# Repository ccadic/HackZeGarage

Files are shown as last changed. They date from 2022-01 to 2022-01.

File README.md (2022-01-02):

# HackZeGarage
ESP32-S2 and CC1101S 433Mhz usb stick to record and send car gates/garages data keys and open stuff

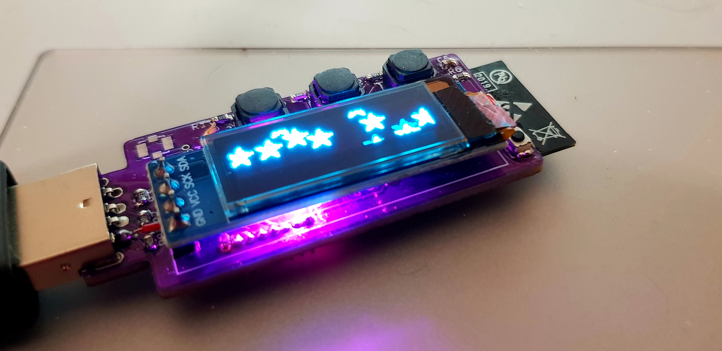
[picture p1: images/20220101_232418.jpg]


**HackZeGarage

@sulfuroid / Dr CADIC Philippe
Portable USB Stick to replace garage doors and gate doors remote controls into one single 433 Mhz C1101 transceiver device. Data bank of gates digital signatures. 

The ESP32 C1101 USB stick to ease the access to garages and parkings using 433 Mhz remote keys. HackZeGarage is a USB stick with ESP32 S2, battery and charging module with 3 buttons and a SSD1306 Oled display. This item can also be used as a passwords data bank.

**UPLOADING SKETCHES**

Uploading sketches onto an ESP32S2 is a bit tricky. You have to plug the device onto the USB port of the PC running Arduino IDE. Then, you have to press RST and BOOT micro switch respecting this order :
1.	Press both  RESET & BOOT switches
2.	Release RESET switch
3.	Then release BOOT
If it is done properly , you should ear the computer recognize the device and a COMx port should appear.

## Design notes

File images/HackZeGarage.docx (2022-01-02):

HackZeGarage
@sulfuroid / Dr CADIC Philippe

Portable USB Stick to replace garage doors and gate doors remote controls into one single 433 Mhz C1101 transceiver device. Data bank of gates digital signatures.

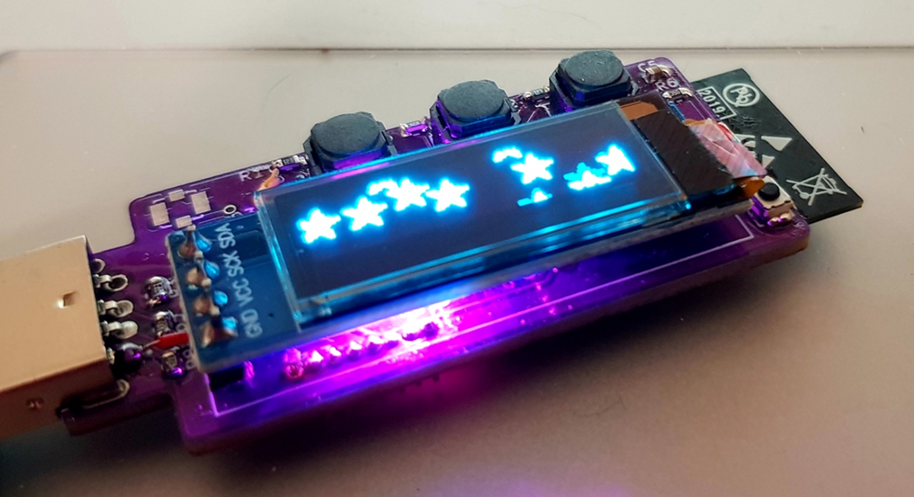
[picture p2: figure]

The ESP32 C1101 USB stick to ease the access to garages and parkings using 433 Mhz remote keys. HackZeGarage is a USB stick with ESP32 S2, battery and charging module with 3 buttons and a SSD1306 Oled display. This item can also be used as a password data bank.

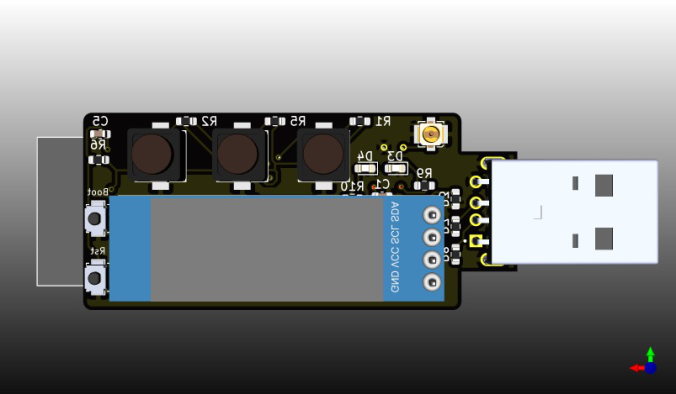
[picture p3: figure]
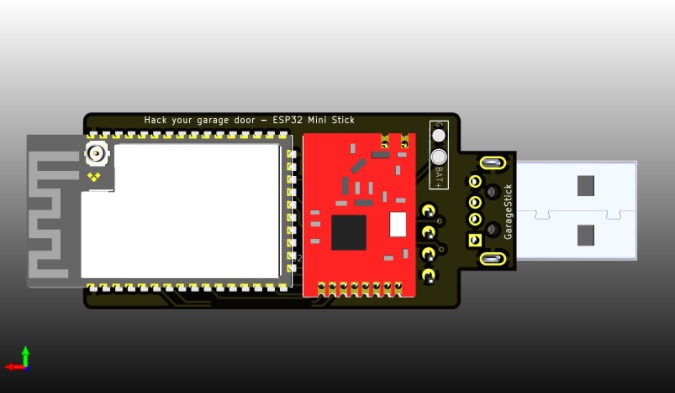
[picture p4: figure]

List of components

- 2 micro switches for ESP32 BOOT/RESET options
- 3 buttons on the top of the display
  - SW1/BUTTON3/GPIO 01
  - SW4/BUTTON1/GPIO 15
  - SW5/BUTTON2/GPIO 16
- 2 configurable LEDs
  - D3 : GPIO 21
  - D4 : GPIO 14
- A 128x32 SSD1306 OLD Display (I2C connected). The display’s power is controlled by GPIO 06
- A 433 MHZ SPI transceiver module. This device is also power controlled with GPIO 7

Schematic diagram

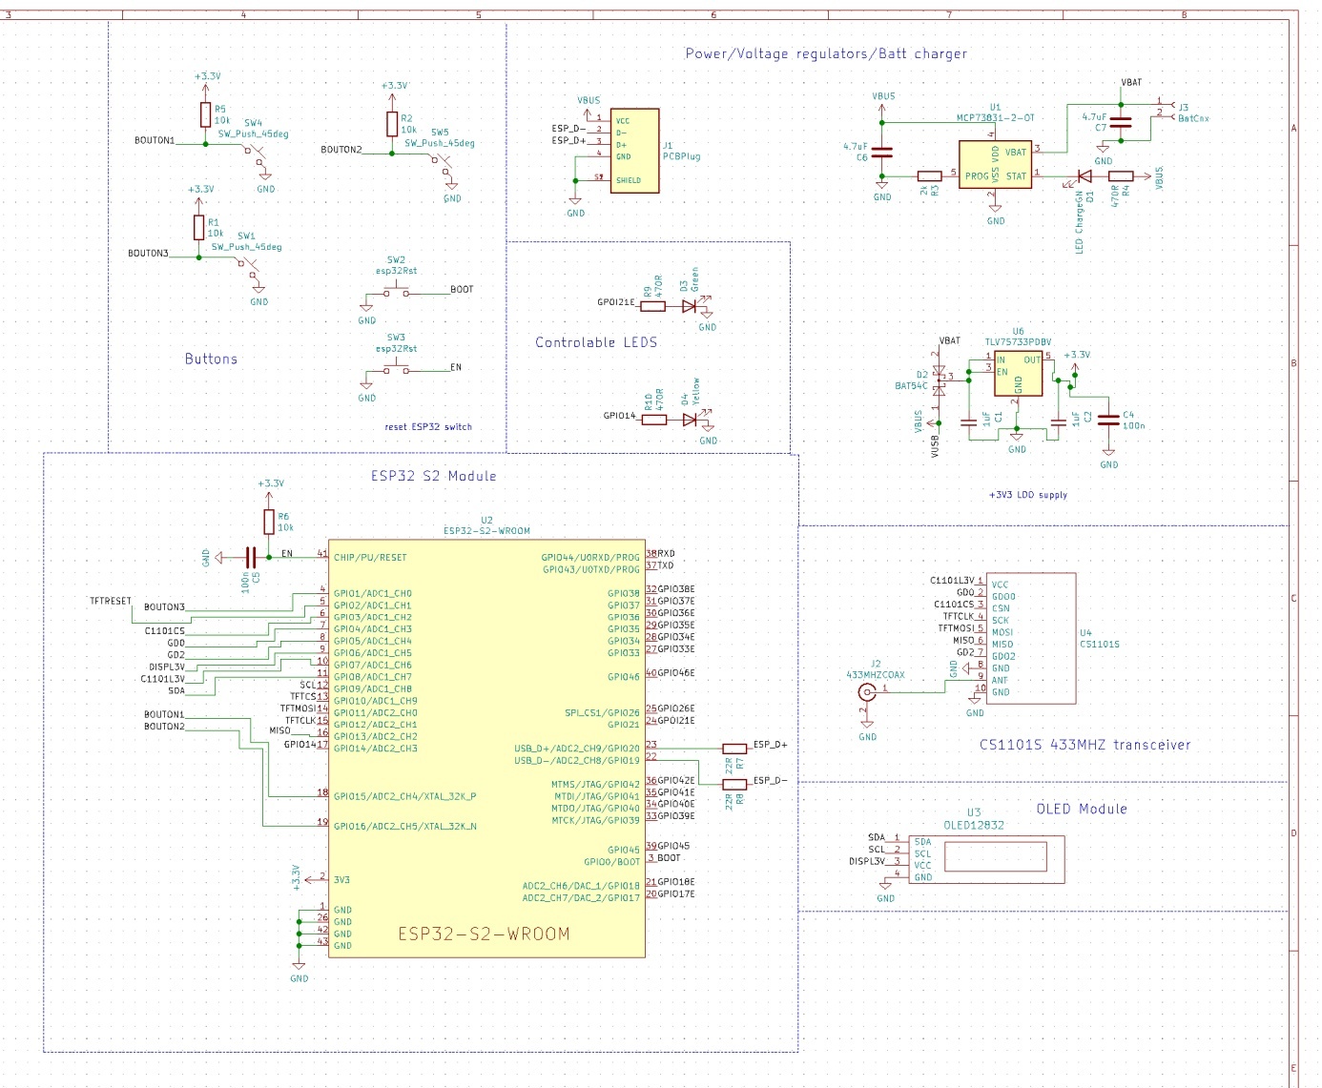
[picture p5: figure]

UPLOADING SKETCHES

Uploading sketches onto an ESP32S2 is a bit tricky. You have to plug the device onto the USB port of the PC running Arduino IDE. Then, you have to press RST and BOOT micro switch respecting this order :

1. Press both RESET & BOOT switches
2. Release RESET switch
3. Then release BOOT

If it is done properly , you should ear the computer recognize the device and a COMx port should appear.

ARDUINO IDE setup

The ESP32S2 is capable or direct USB connection. You have to select ESP32S2 DEV MODULE and select the option as shown in the image above.

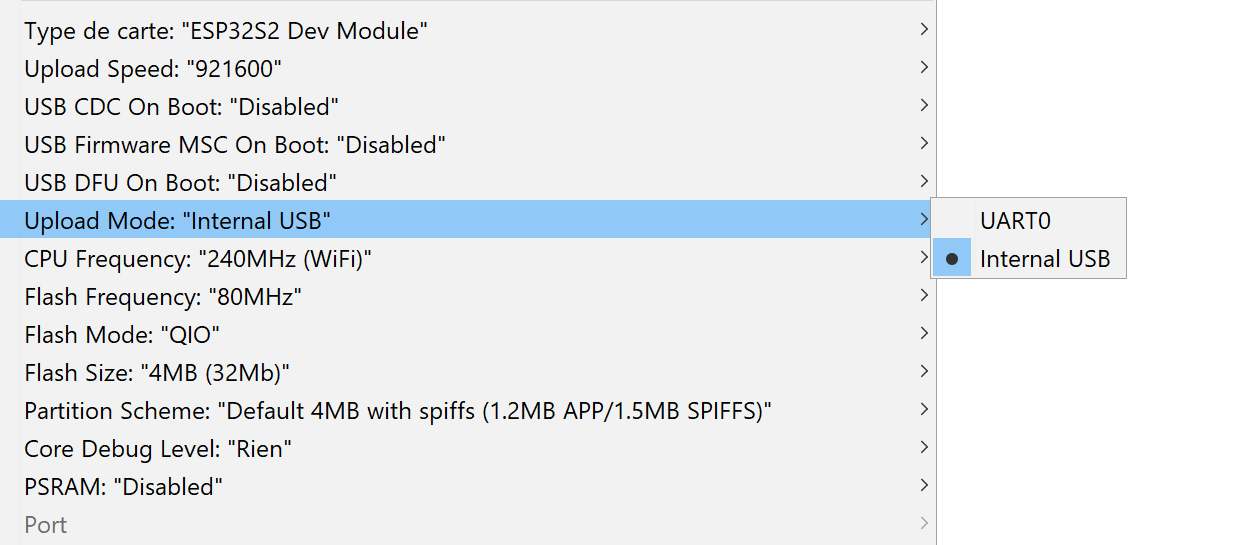
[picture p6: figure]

BOM : see BOM.XLS

This board has been designed to keep the budget as low as possible. Most of the components are classic components you may find everywhere.

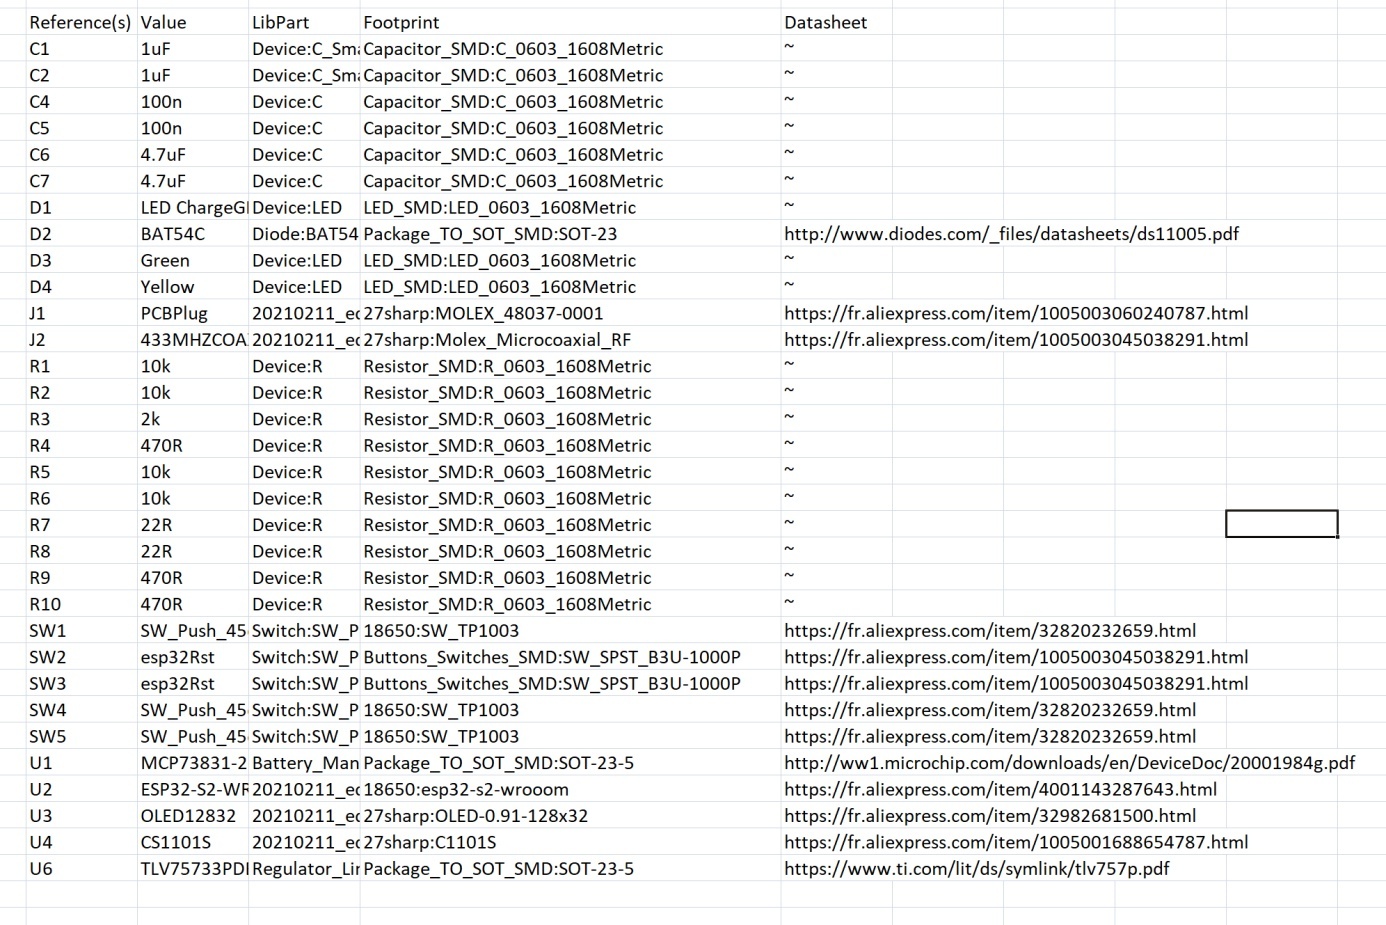
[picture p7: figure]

Important note:

You may get the 0.3 version of the board which has to issues you can easily fix. Beside this fix, there is no difference with V1 version. To protect the environment of our planet, we decided not to through the 50 V0.3 PCB to the bin as the fix is minor. If you get the V0.3 version, you will need to add 2 extra wires when assembling the device. See diagram above.

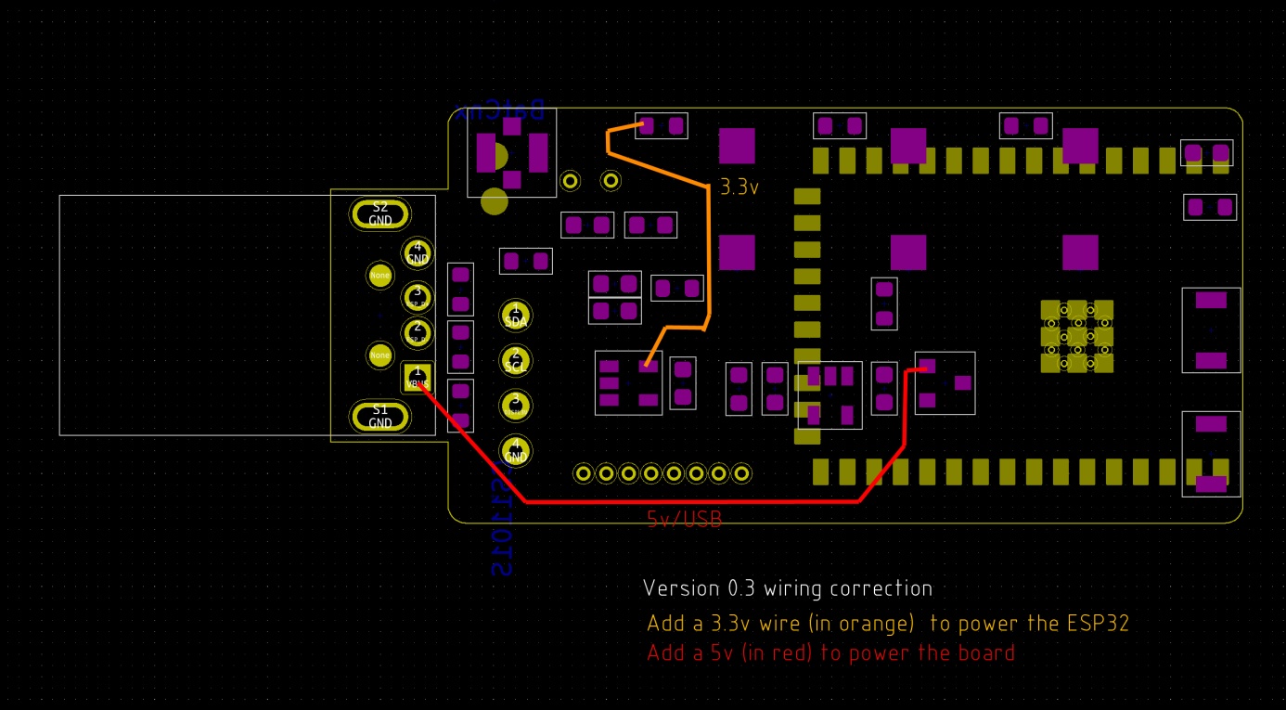
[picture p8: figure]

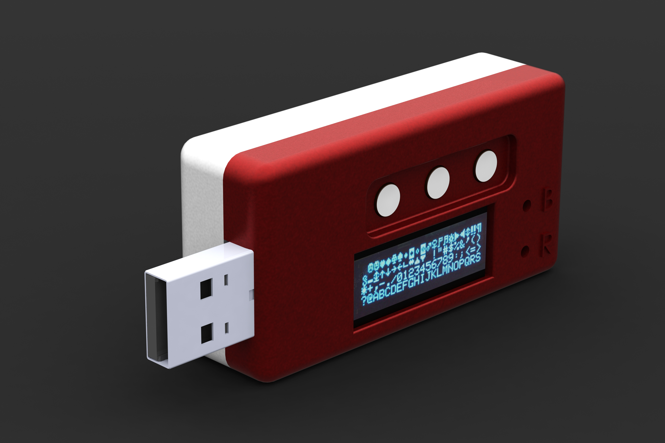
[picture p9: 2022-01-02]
allstuff3.JPG

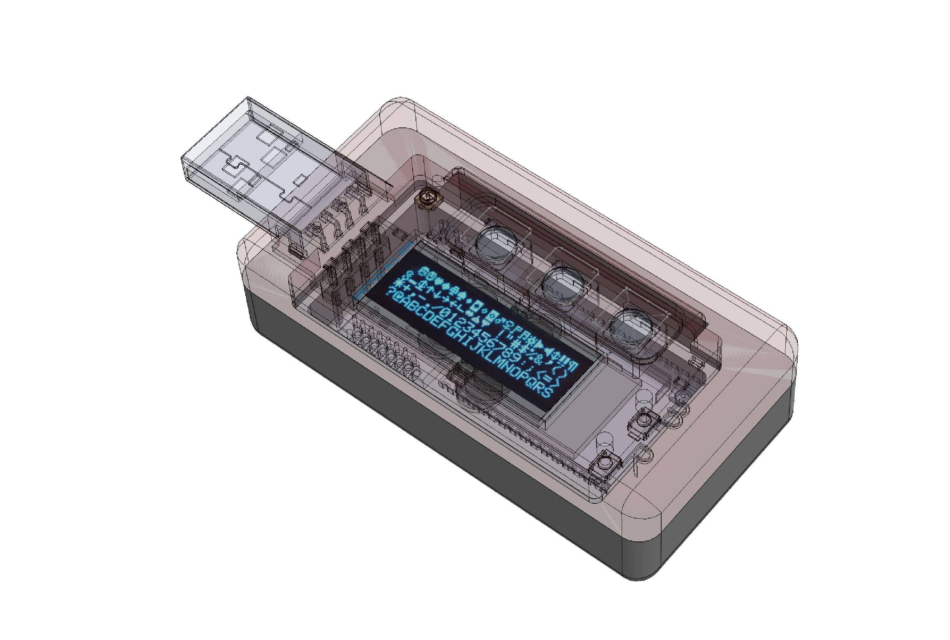
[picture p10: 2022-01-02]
allstuff4.JPG

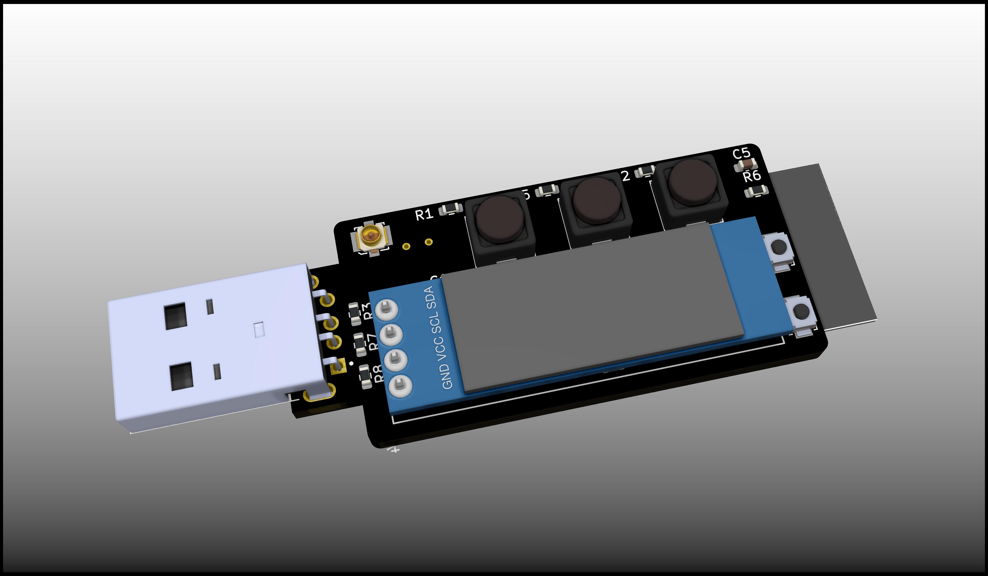
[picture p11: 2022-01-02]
images/keyring.jpg

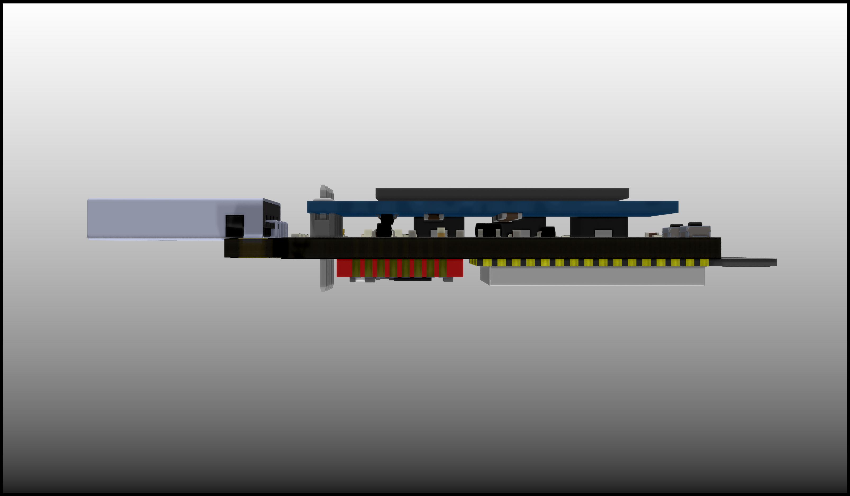
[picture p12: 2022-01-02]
images/keyringgarage4.jpg

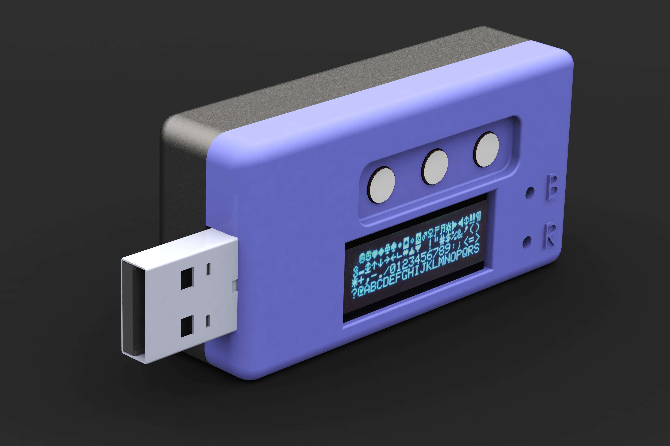
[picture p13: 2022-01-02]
allstuff5.JPG

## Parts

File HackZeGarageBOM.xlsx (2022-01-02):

Source: | C:\Users\ccadic\CloudStation\garagehack\version2\20210211_eduino.sch
Date: | 2022-01-02 14:31
Tool: | Eeschema (5.1.12)-1
Generator: | C:\Program Files\KiCad\bin\scripting\plugins/bom_csv_grouped_by_value.py
Component Count: | 33
Individual Components:
Item | Qty | Reference(s) | Value | LibPart | Footprint | Datasheet
 |  | C1 | 1uF | Device:C_Small | Capacitor_SMD:C_0603_1608Metric | ~
 |  | C2 | 1uF | Device:C_Small | Capacitor_SMD:C_0603_1608Metric | ~
 |  | C4 | 100n | Device:C | Capacitor_SMD:C_0603_1608Metric | ~
 |  | C5 | 100n | Device:C | Capacitor_SMD:C_0603_1608Metric | ~
 |  | C6 | 4.7uF | Device:C | Capacitor_SMD:C_0603_1608Metric | ~
 |  | C7 | 4.7uF | Device:C | Capacitor_SMD:C_0603_1608Metric | ~
 |  | D1 | LED ChargeGN | Device:LED | LED_SMD:LED_0603_1608Metric | ~
 |  | D2 | BAT54C | Diode:BAT54C | Package_TO_SOT_SMD:SOT-23 | http://www.diodes.com/_files/datasheets/ds11005.pdf
 |  | D3 | Green | Device:LED | LED_SMD:LED_0603_1608Metric | ~
 |  | D4 | Yellow | Device:LED | LED_SMD:LED_0603_1608Metric | ~
 |  | J1 | PCBPlug | 20210211_eduino-rescue:48037-0001-4g_ant | 27sharp:MOLEX_48037-0001 | https://fr.aliexpress.com/item/1005003060240787.html
 |  | J2 | 433MHZCOAX | 20210211_eduino-rescue:Conn_Coaxial-ConnectorPCI-conn_coaxial-connectorpci | 27sharp:Molex_Microcoaxial_RF | https://fr.aliexpress.com/item/1005003045038291.html
 |  | R1 | 10k | Device:R | Resistor_SMD:R_0603_1608Metric | ~
 |  | R2 | 10k | Device:R | Resistor_SMD:R_0603_1608Metric | ~
 |  | R3 | 2k | Device:R | Resistor_SMD:R_0603_1608Metric | ~
 |  | R4 | 470R | Device:R | Resistor_SMD:R_0603_1608Metric | ~
 |  | R5 | 10k | Device:R | Resistor_SMD:R_0603_1608Metric | ~
 |  | R6 | 10k | Device:R | Resistor_SMD:R_0603_1608Metric | ~
 |  | R7 | 22R | Device:R | Resistor_SMD:R_0603_1608Metric | ~
 |  | R8 | 22R | Device:R | Resistor_SMD:R_0603_1608Metric | ~
 |  | R9 | 470R | Device:R | Resistor_SMD:R_0603_1608Metric | ~
 |  | R10 | 470R | Device:R | Resistor_SMD:R_0603_1608Metric | ~
 |  | SW1 | SW_Push_45deg | Switch:SW_Push_45deg | 18650:SW_TP1003 | https://fr.aliexpress.com/item/32820232659.html
 |  | SW2 | esp32Rst | Switch:SW_Push | Buttons_Switches_SMD:SW_SPST_B3U-1000P | https://fr.aliexpress.com/item/1005003045038291.html
 |  | SW3 | esp32Rst | Switch:SW_Push | Buttons_Switches_SMD:SW_SPST_B3U-1000P | https://fr.aliexpress.com/item/1005003045038291.html
 |  | SW4 | SW_Push_45deg | Switch:SW_Push_45deg | 18650:SW_TP1003 | https://fr.aliexpress.com/item/32820232659.html
 |  | SW5 | SW_Push_45deg | Switch:SW_Push_45deg | 18650:SW_TP1003 | https://fr.aliexpress.com/item/32820232659.html
 |  | U1 | MCP73831-2-OT | Battery_Management:MCP73831-2-OT | Package_TO_SOT_SMD:SOT-23-5 | http://ww1.microchip.com/downloads/en/DeviceDoc/20001984g.pdf
 |  | U2 | ESP32-S2-WROOM | 20210211_eduino-rescue:ESP32-S2-WROOM-EspressifC3 | 18650:esp32-s2-wrooom | https://fr.aliexpress.com/item/4001143287643.html
 |  | U3 | OLED12832 | 20210211_eduino-rescue:OLED12832-oled12832 | 27sharp:OLED-0.91-128x32 | https://fr.aliexpress.com/item/32982681500.html
 |  | U4 | CS1101S | 20210211_eduino-rescue:CS1101S-CS1101S | 27sharp:C1101S | https://fr.aliexpress.com/item/1005001688654787.html
 |  | U6 | TLV75733PDBV | Regulator_Linear:TLV75733PDBV | Package_TO_SOT_SMD:SOT-23-5 | https://www.ti.com/lit/ds/symlink/tlv757p.pdf
Collated Components:
Item | Qty | Reference(s) | Value | LibPart | Footprint | Datasheet
1 | 2 | C1; C2 | 1uF | Device:C_Small | Capacitor_SMD:C_0603_1608Metric | ~
2 | 2 | C4; C5 | 100n | Device:C | Capacitor_SMD:C_0603_1608Metric | ~
3 | 2 | C6; C7 | 4.7uF | Device:C | Capacitor_SMD:C_0603_1608Metric | ~
4 | 1 | D1 | LED ChargeGN | Device:LED | LED_SMD:LED_0603_1608Metric | ~
5 | 1 | D2 | BAT54C | Diode:BAT54C | Package_TO_SOT_SMD:SOT-23 | http://www.diodes.com/_files/datasheets/ds11005.pdf
6 | 1 | D3 | Green | Device:LED | LED_SMD:LED_0603_1608Metric | ~
7 | 1 | D4 | Yellow | Device:LED | LED_SMD:LED_0603_1608Metric | ~
8 | 1 | J1 | PCBPlug | 20210211_eduino-rescue:48037-0001-4g_ant | 27sharp:MOLEX_48037-0001
9 | 1 | J2 | 433MHZCOAX | 20210211_eduino-rescue:Conn_Coaxial-ConnectorPCI-conn_coaxial-connectorpci | 27sharp:Molex_Microcoaxial_RF
10 | 1 | J3 | BatCnx | Connector:Conn_01x02_Female | 18650:2pads | ~
11 | 4 | R1; R2; R5; R6 | 10k | Device:R | Resistor_SMD:R_0603_1608Metric | ~
12 | 1 | R3 | 2k | Device:R | Resistor_SMD:R_0603_1608Metric | ~
13 | 3 | R4; R9; R10 | 470R | Device:R | Resistor_SMD:R_0603_1608Metric | ~
14 | 2 | R7; R8 | 22R | Device:R | Resistor_SMD:R_0603_1608Metric | ~
15 | 3 | SW1; SW4; SW5 | SW_Push_45deg | Switch:SW_Push_45deg | 18650:SW_TP1003 | ~
16 | 2 | SW2; SW3 | esp32Rst | Switch:SW_Push | Buttons_Switches_SMD:SW_SPST_B3U-1000P | ~
17 | 1 | U1 | MCP73831-2-OT | Battery_Management:MCP73831-2-OT | Package_TO_SOT_SMD:SOT-23-5 | http://ww1.microchip.com/downloads/en/DeviceDoc/20001984g.pdf
18 | 1 | U2 | ESP32-S2-WROOM | 20210211_eduino-rescue:ESP32-S2-WROOM-EspressifC3 | 18650:esp32-s2-wrooom
19 | 1 | U3 | OLED12832 | 20210211_eduino-rescue:OLED12832-oled12832 | 27sharp:OLED-0.91-128x32
20 | 1 | U4 | CS1101S | 20210211_eduino-rescue:CS1101S-CS1101S | 27sharp:C1101S
21 | 1 | U6 | TLV75733PDBV | Regulator_Linear:TLV75733PDBV | Package_TO_SOT_SMD:SOT-23-5 | https://www.ti.com/lit/ds/symlink/tlv757p.pdf

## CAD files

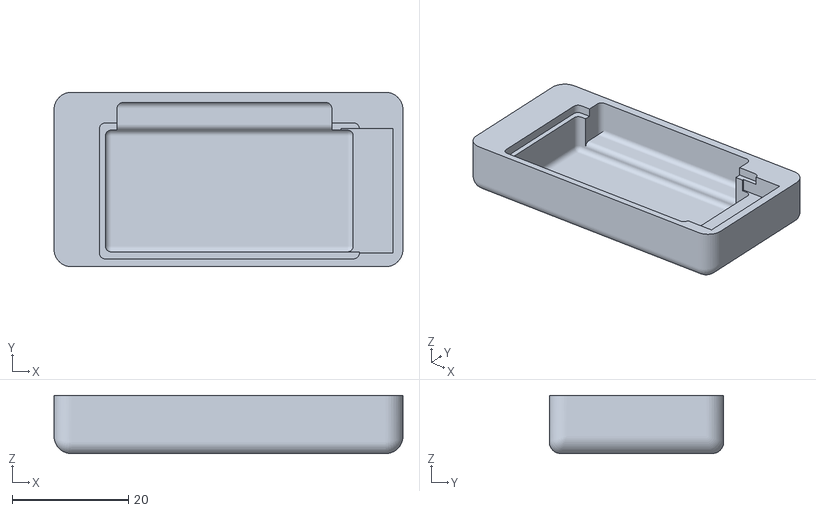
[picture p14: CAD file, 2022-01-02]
stl/coqueinf-batt.STL
60.0 x 30.0 x 10.0

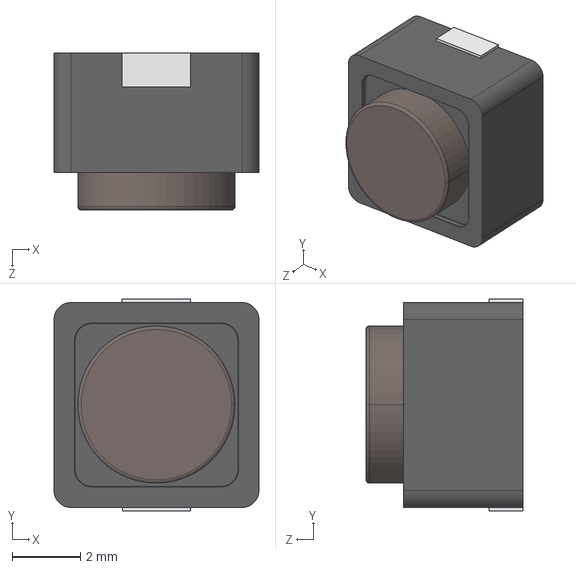
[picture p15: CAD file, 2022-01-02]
TP1003.STEP
6.00 x 6.20 x 4.60 mm

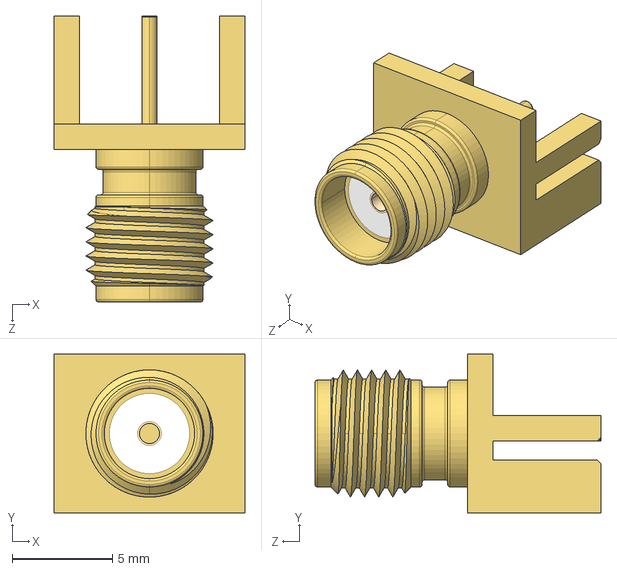
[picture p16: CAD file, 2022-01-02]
sma_fem.STEP
9.52 x 7.92 x 14.3 mm

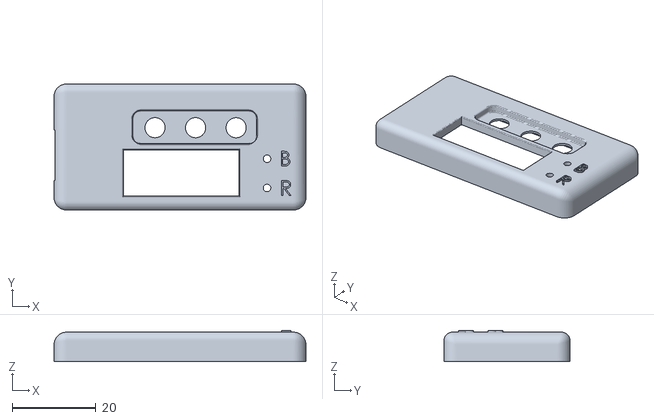
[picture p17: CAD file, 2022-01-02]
stl/coque sup.STL
60.0 x 30.0 x 7.40

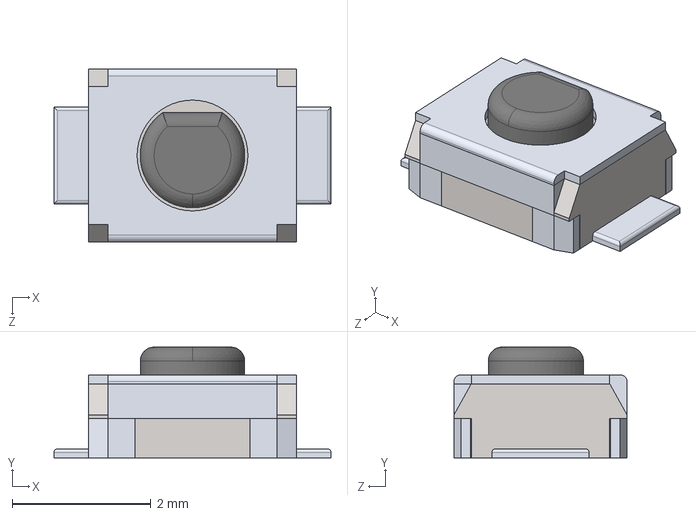
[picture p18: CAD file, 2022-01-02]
B3U1000P.step
4.00 x 1.60 x 2.50 mm

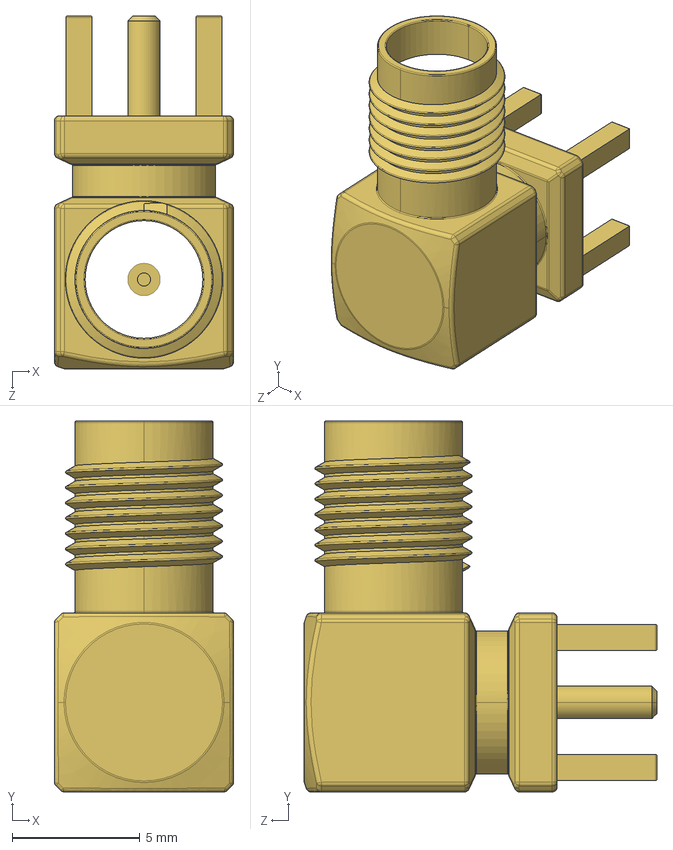
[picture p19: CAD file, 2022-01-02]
SMA-angled.STEP
7.00 x 14.5 x 13.8 mm

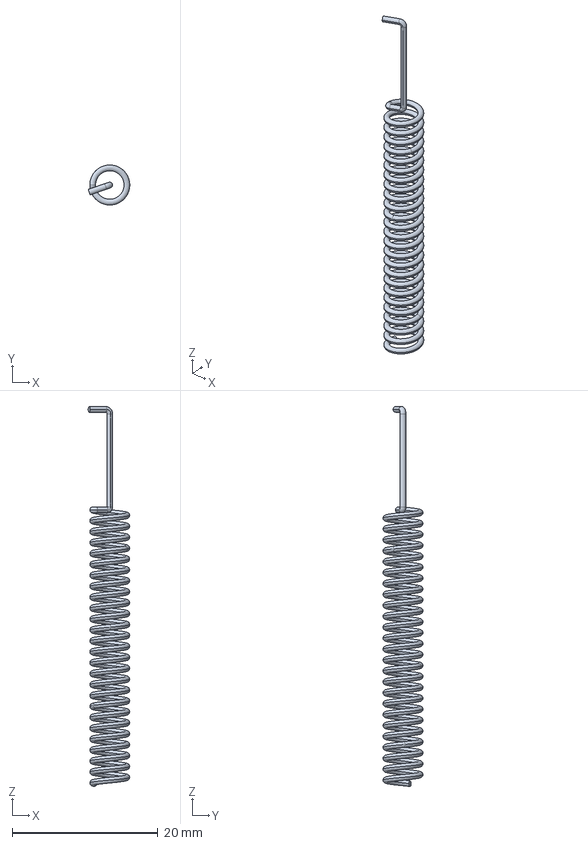
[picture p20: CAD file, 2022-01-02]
433mhz_antenna_bended.stp
5.72 x 5.50 x 52.2 mm

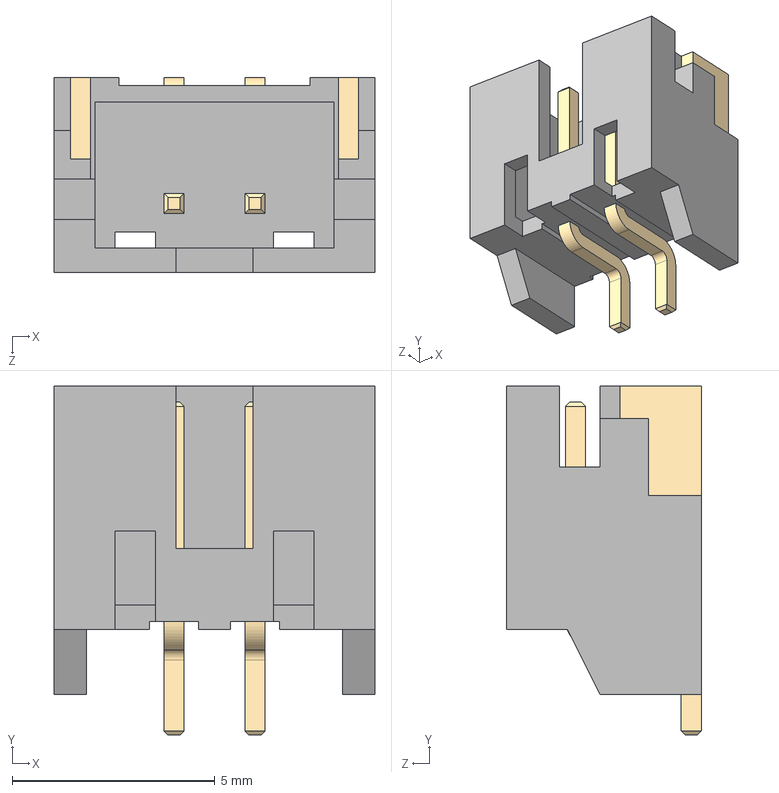
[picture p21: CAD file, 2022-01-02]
JST-PH 2-Pin.STEP
7.90 x 8.60 x 4.80 mm

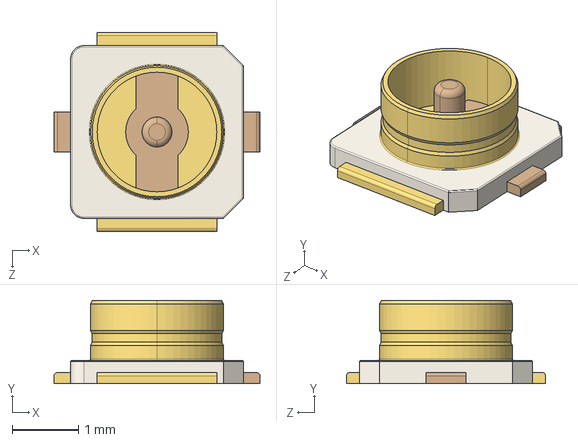
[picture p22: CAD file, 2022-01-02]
coax.STEP
3.10 x 1.25 x 3.00 mm

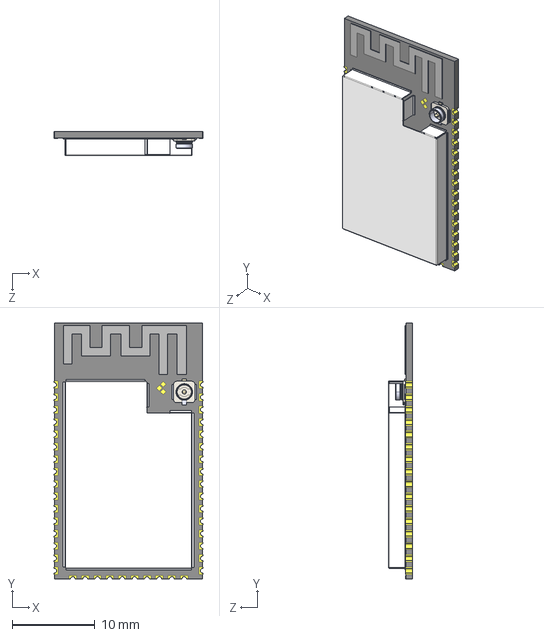
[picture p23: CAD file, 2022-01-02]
ESP32-S2-WROVER.STEP
18.0 x 31.0 x 2.91 mm

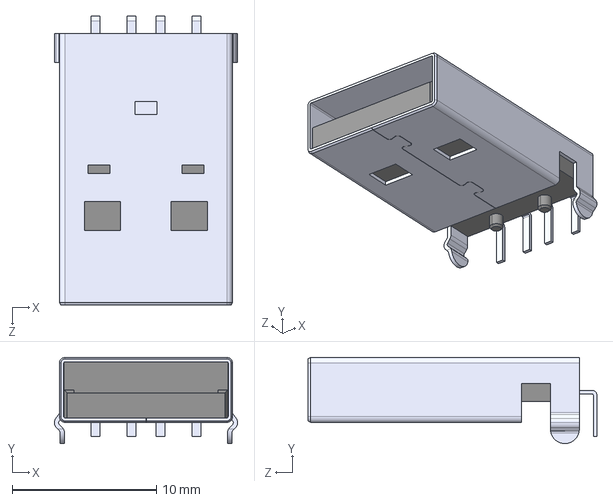
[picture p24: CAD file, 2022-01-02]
48037-0001.step
12.7 x 5.97 x 20.0 mm

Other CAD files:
48037-0001.stp

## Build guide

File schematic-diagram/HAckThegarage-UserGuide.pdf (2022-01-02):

# HackZeGarage

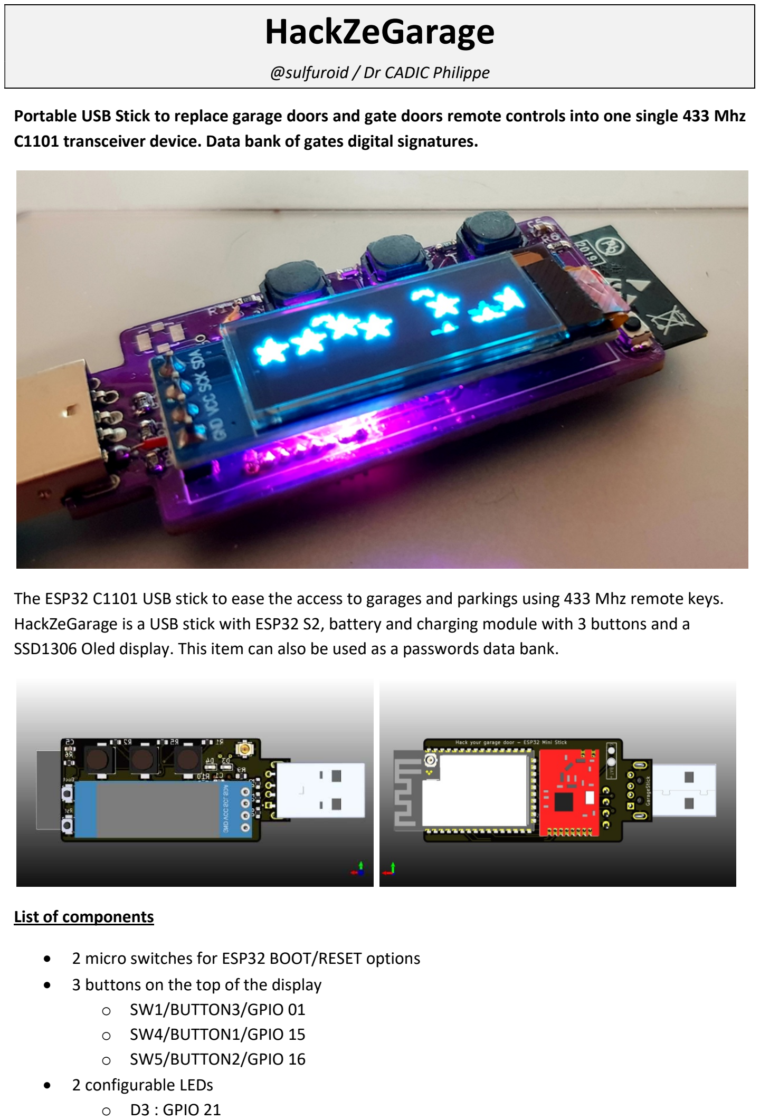
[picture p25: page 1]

@sulfuroid / Dr CADIC Philippe

Portable USB Stick to replace garage doors and gate doors remote controls into one single 433 Mhz C1101 transceiver device. Data bank of gates digital signatures.

The ESP32 C1101 USB stick to ease the access to garages and parkings using 433 Mhz remote keys. HackZeGarage is a USB stick with ESP32 S2, battery and charging module with 3 buttons and a SSD1306 Oled display. This item can also be used as a passwords data bank.

List of components

- 2 micro switches for ESP32 BOOT/RESET options
- 3 buttons on the top of the display
o SW1/BUTTON3/GPIO 01
o SW4/BUTTON1/GPIO 15
o SW5/BUTTON2/GPIO 16
- 2 configurable LEDs
o D3 : GPIO 21

o D4 : GPIO 14
- A 128x32 SSD1306 OLD Display (I2C connected). The display’s power is controlled by GPIO 06
- A 433 MHZ SPI transceiver module. This device is also power controlled with GPIO 7

Schematic diagram


UPLOADING SKETCHES

Uploading sketches onto an ESP32S2 is a bit tricky. You have to plug the device onto the USB port of the PC running Arduino IDE. Then, you have to press RST and BOOT micro switch respecting this order :

### 1. Press both RESET & BOOT switches 2. Release RESET switch 3. Then release BOOT

If it is done properly , you should ear the computer recognize the device and a COMx port should appear.

ARDUINO IDE setup

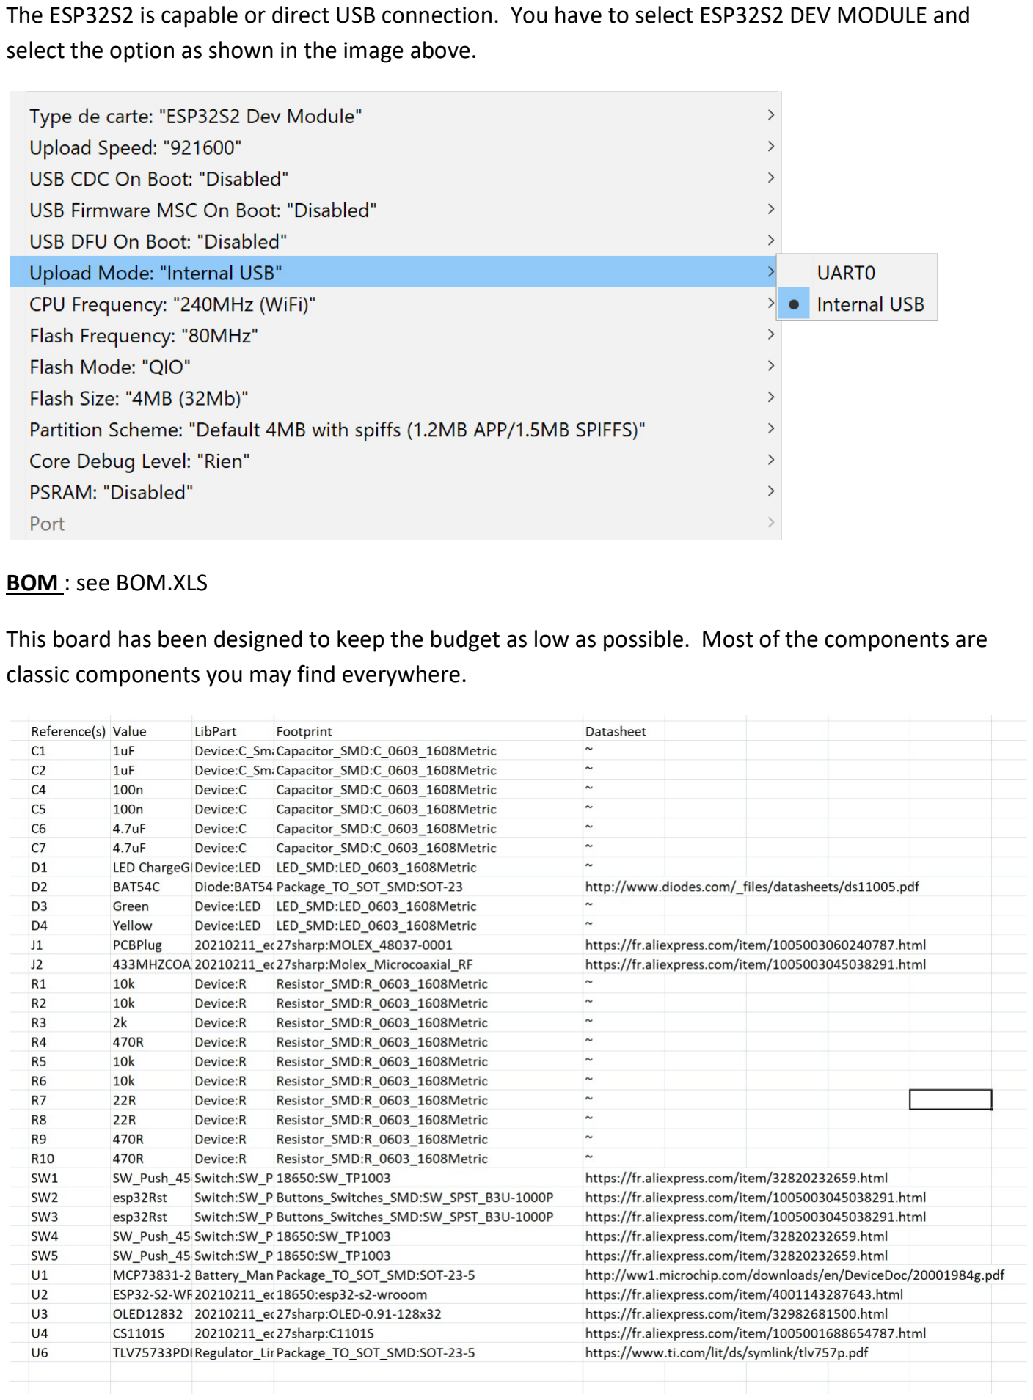
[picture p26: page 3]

The ESP32S2 is capable or direct USB connection. You have to select ESP32S2 DEV MODULE and select the option as shown in the image above.

BOM : see BOM.XLS

This board has been designed to keep the budget as low as possible. Most of the components are classic components you may find everywhere.

Important note:

You may get the 0.3 version of the board which has to issues you can easily fix. Beside this fix, there is no difference with V1 version. To protect the environment of our planet, we decided not to through the 50 V0.3 PCB to the bin as the fix is minor. If you get the V0.3 version, you will need to add 2 extra wires when assembling the device. See diagram above.


GitHUB documentation

https://github.com/ccadic/HackZeGarage

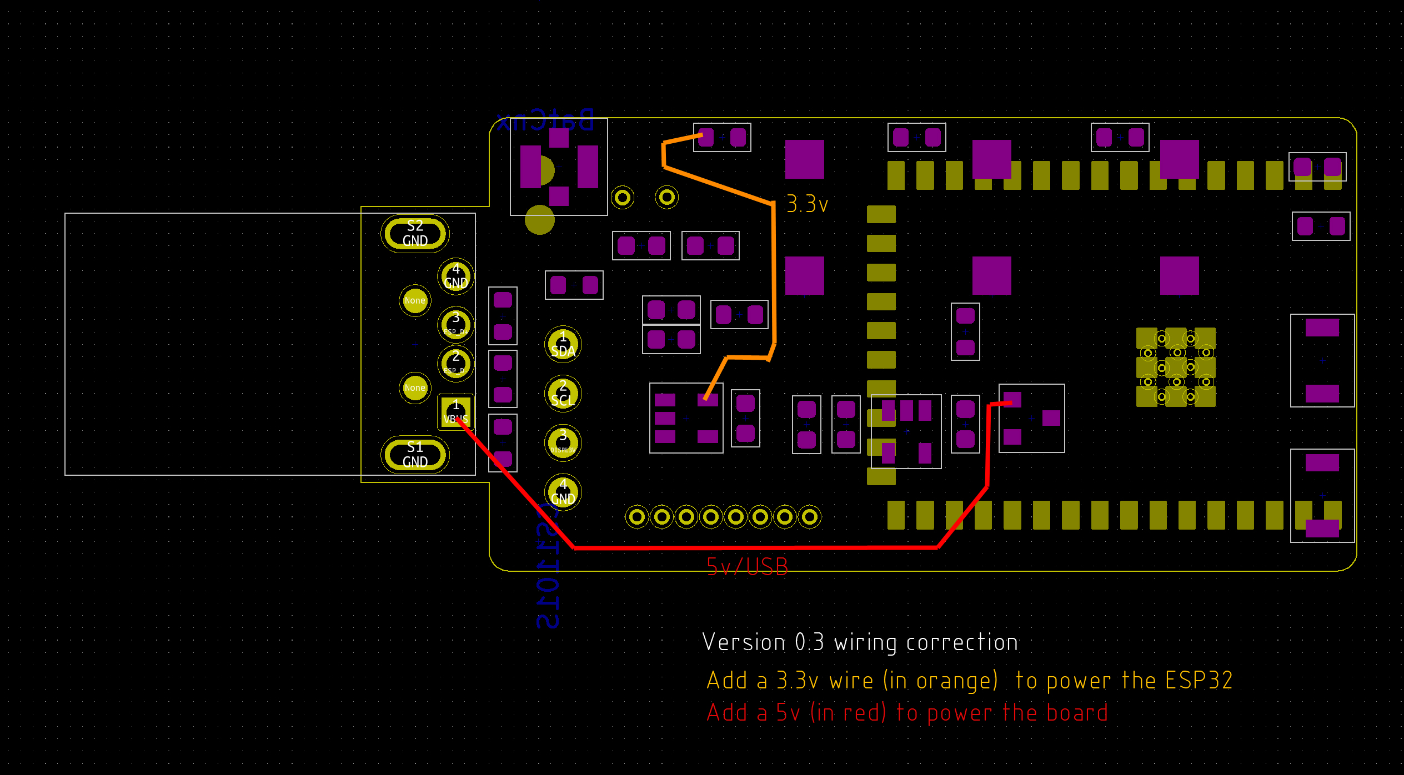
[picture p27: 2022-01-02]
images/wiring_correction.jpg

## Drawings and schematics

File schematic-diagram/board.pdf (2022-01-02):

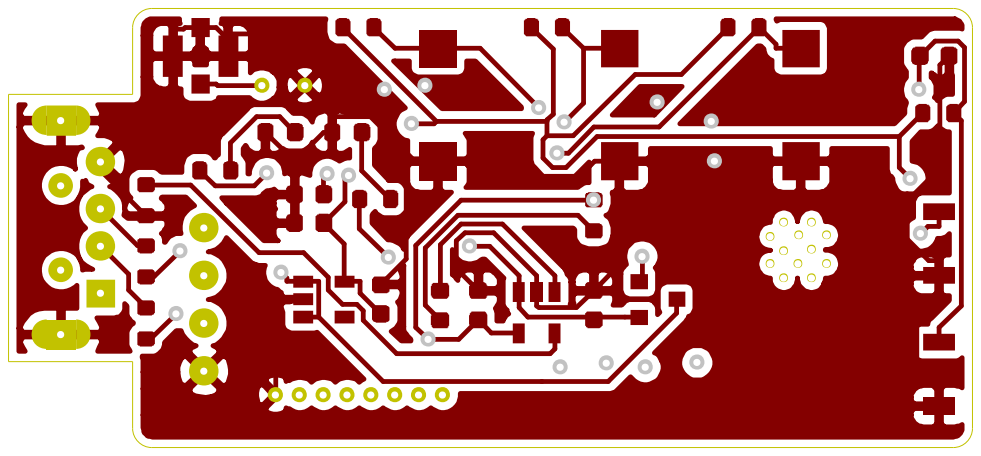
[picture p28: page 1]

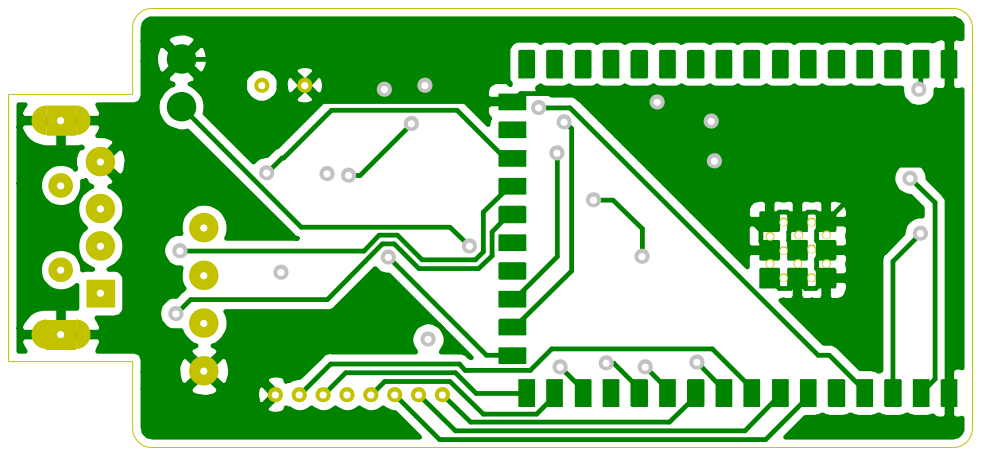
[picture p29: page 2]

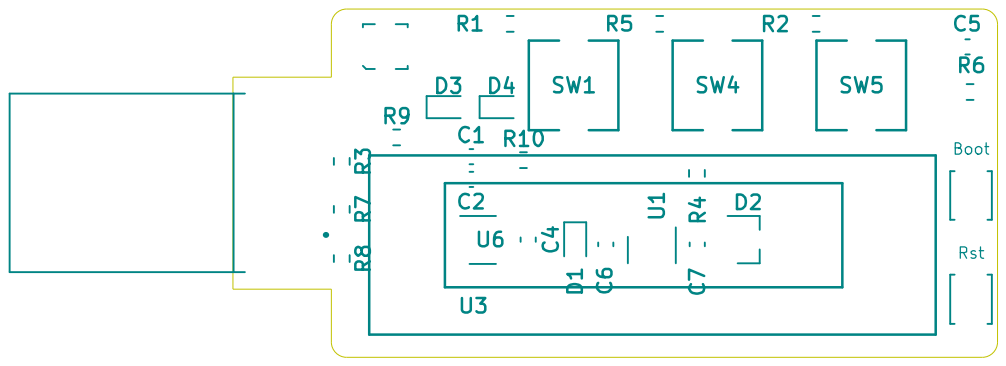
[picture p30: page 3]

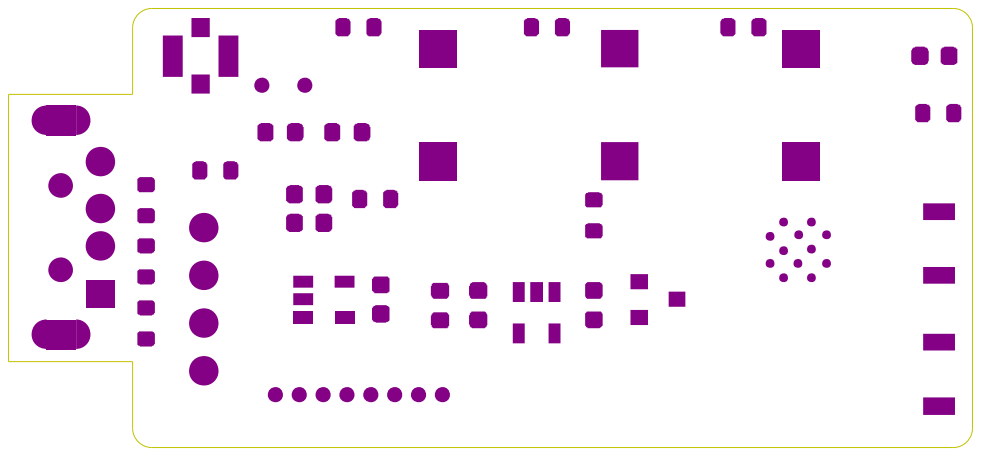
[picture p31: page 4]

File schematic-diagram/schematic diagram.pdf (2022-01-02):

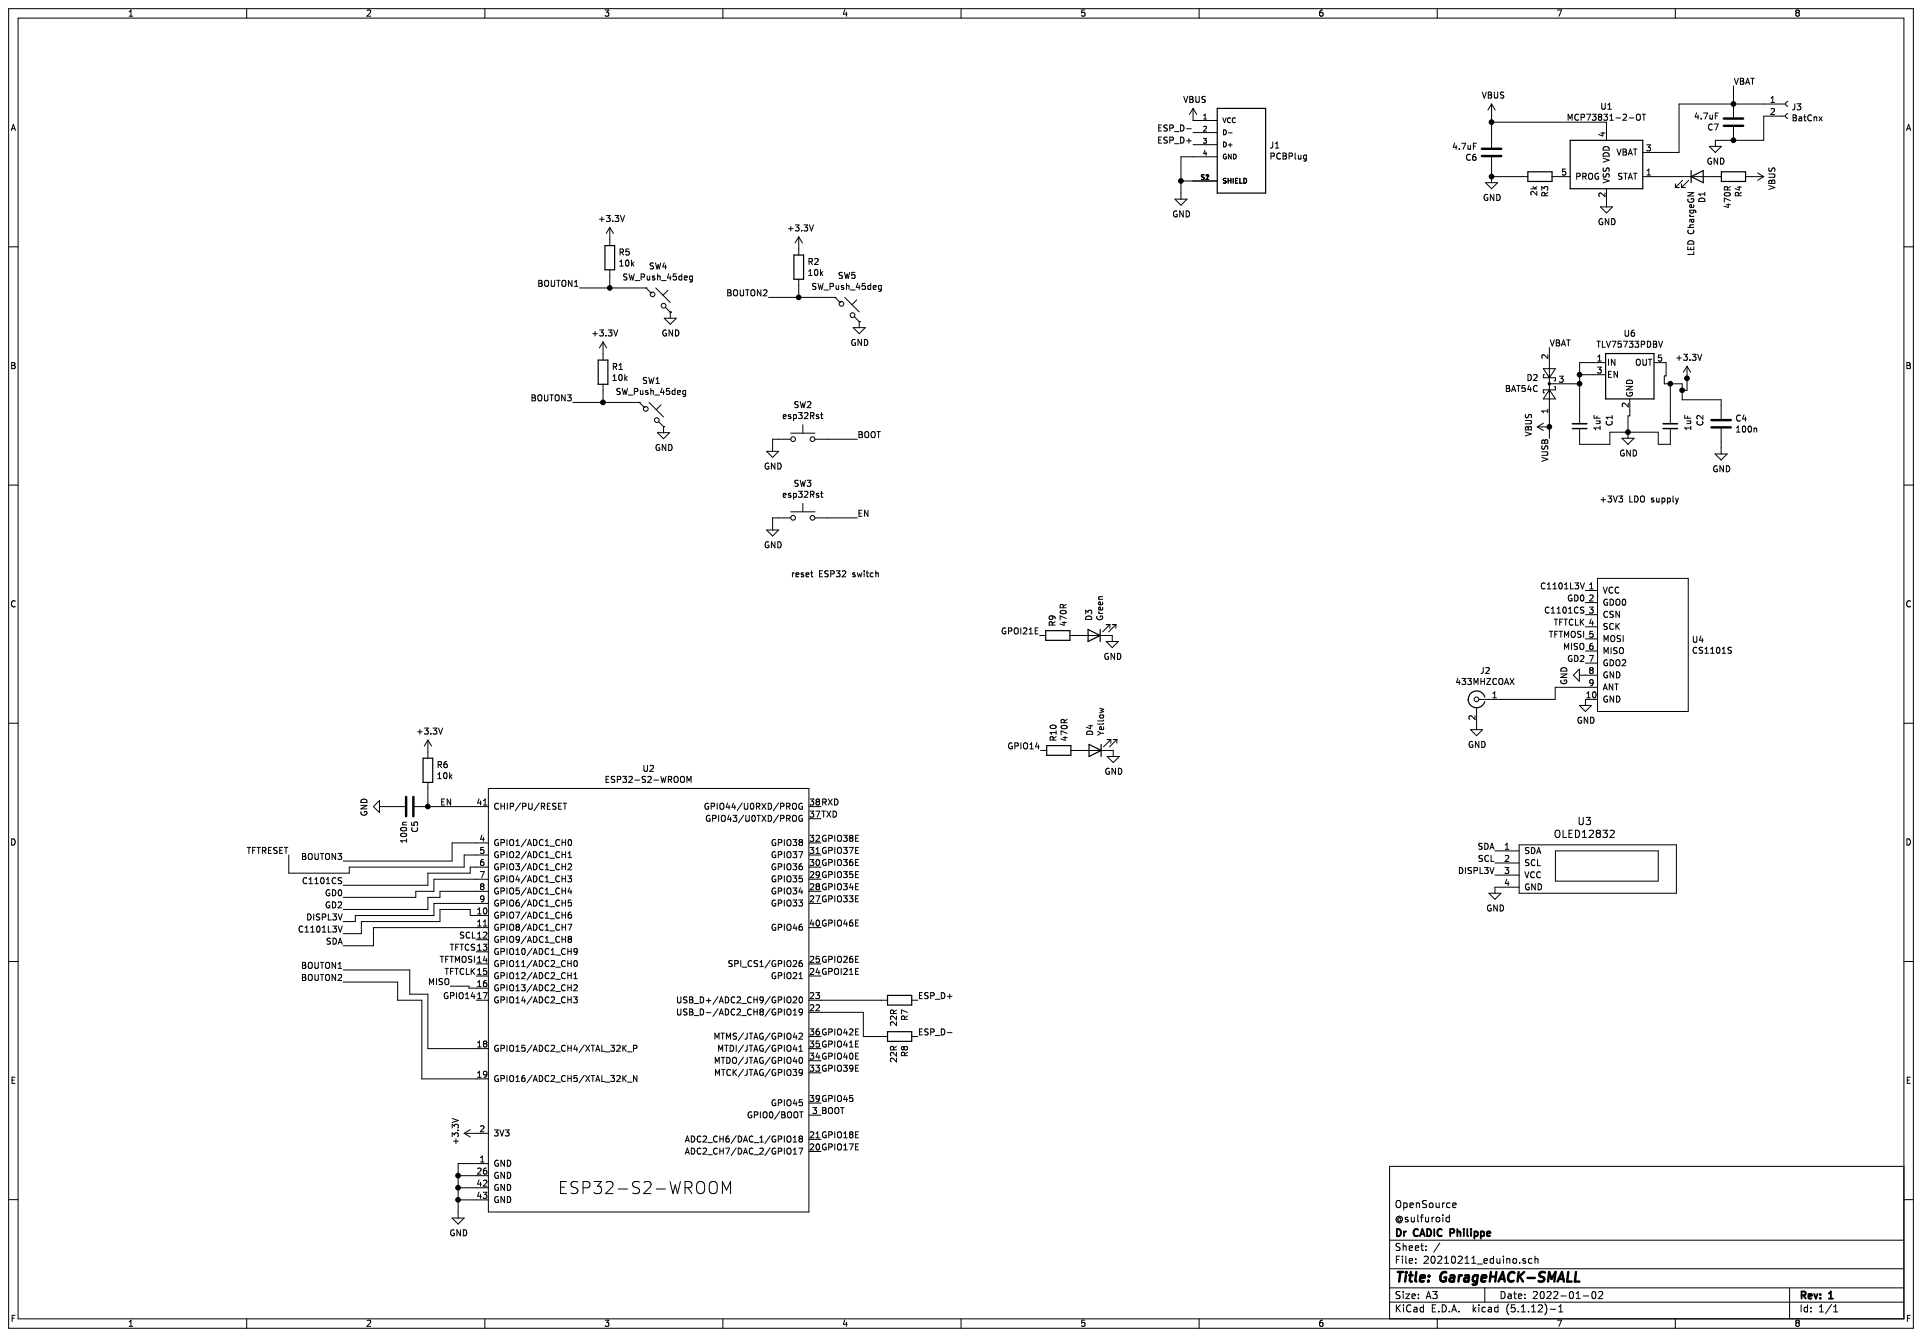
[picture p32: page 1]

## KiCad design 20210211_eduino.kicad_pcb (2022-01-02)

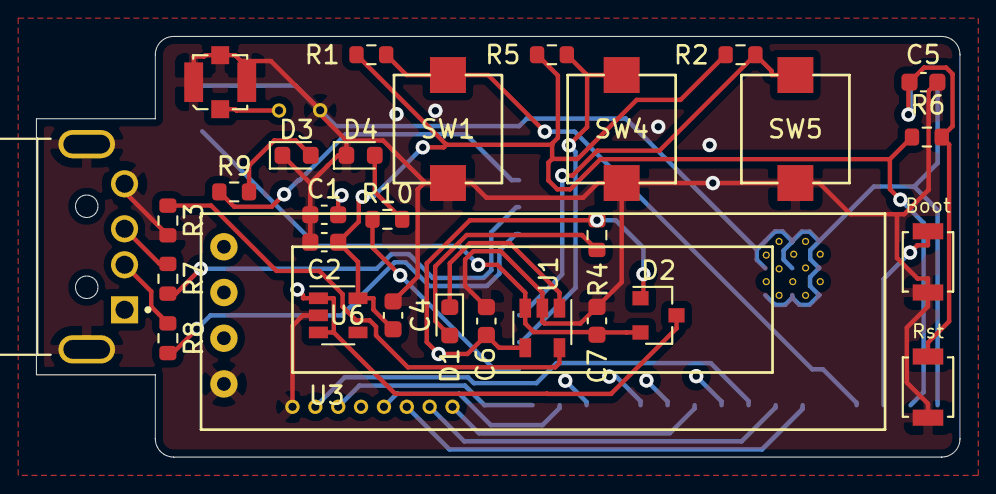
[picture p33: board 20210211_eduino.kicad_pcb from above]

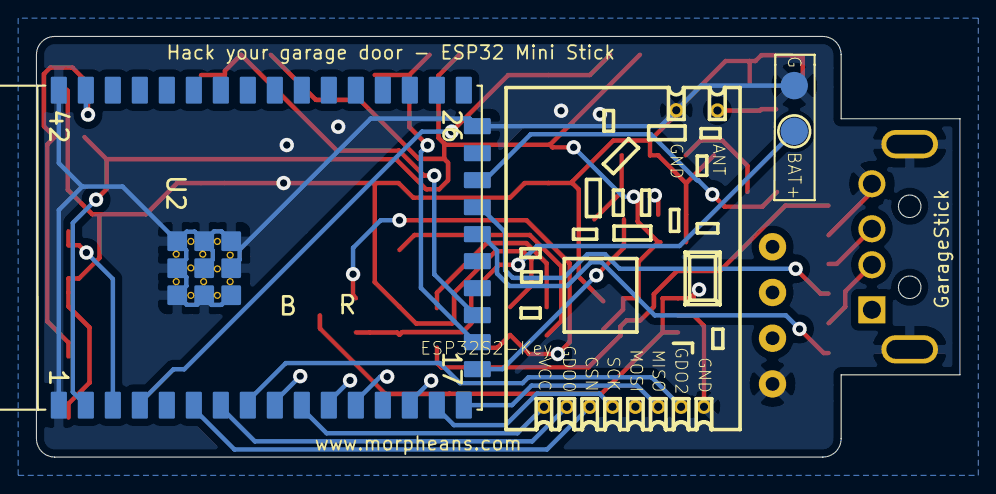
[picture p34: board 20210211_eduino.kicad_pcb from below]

Board: 4 copper layers, 51.3 x 23.4 mm, 33 parts (3 on the bottom side), 32 nets.

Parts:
C1, C2: 1uF; C_0603_1608Metric
C4, C5: 100n; C_0603_1608Metric
C6, C7: 4.7uF; C_0603_1608Metric
D1: LED ChargeGN; LED_0603_1608Metric
D2: BAT54C; SOT-23
D3: Green; LED_0603_1608Metric
D4: Yellow; LED_0603_1608Metric
J1: PCBPlug; MOLEX_48037-0001
J2: 433MHZCOAX; Molex_Microcoaxial_RF
J3: BatCnx; 2pads
R1, R2, R5, R6: 10k; R_0603_1608Metric
R3: 2k; R_0603_1608Metric
R4, R9, R10: 470R; R_0603_1608Metric
R7, R8: 22R; R_0603_1608Metric
SW1, SW4, SW5: SW_Push_45deg; SW_TP1003
SW2, SW3: esp32Rst; SW_SPST_B3U-1000P
U1: MCP73831-2-OT; SOT-23-5
U2: ESP32-S2-WROOM; esp32-s2-wrooom
U3: OLED12832; OLED-0.91-128x32
U4: CS1101S; C1101S
U6: TLV75733PDBV; SOT-23-5

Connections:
+3V3: C2.2, C4.1, R1.1, R2.1, R5.1, R6.1, U2.2, U6.5
/BOOT: SW2.2, U2.3
/BOUTON1: R5.2, SW4.1, U2.18
/BOUTON2: R2.2, SW5.1, U2.19
/BOUTON3: R1.2, SW1.1, U2.4
/C1101CS: U2.6, U4.3
/C1101L3V: U2.10, U4.1
/DISPL3V: U2.9, U3.3
/EN: C5.1, R6.2, SW3.2, U2.41
/ESP_D+: J1.3, R7.1
/ESP_D-: J1.2, R8.1
/GD0: U2.7, U4.2
/GD2: U2.8, U4.7
/GPIO14: R10.1, U2.17
/GPOI21E: R9.1, U2.24
/MISO: U2.16, U4.6
/SCL: U2.12, U3.2
/SDA: U2.11, U3.1
/TFTCLK: U2.15, U4.4
/TFTMOSI: U2.14, U4.5
/VBAT: C7.2, D2.2, J3.1, U1.3
GND: C1.1, C2.1, C4.2, C5.2, C6.1, C7.1, D3.1, D4.1, J1.4, J1.S1, J1.S2, J2.2, J3.2, R3.2, SW1.2, SW2.1, SW3.1, SW4.2, SW5.2, U1.2, U2.1, U2.26, U2.42, U2.43, U3.4, U4.8, U4.10, U6.2
unnamed: C1.2, D2.3, U6.1, U6.3
unnamed: D1.1, U1.1
unnamed: D1.2, R4.2
unnamed: D3.2, R9.2
unnamed: D4.2, R10.2
unnamed: J2.1, U4.9
unnamed: R3.1, U1.5
unnamed: R7.2, U2.23
unnamed: R8.2, U2.22
VBUS: C6.2, D2.1, J1.1, R4.1, U1.4

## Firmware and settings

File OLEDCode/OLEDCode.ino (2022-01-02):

/**************************************************************************
 This is an example for our Monochrome OLEDs based on SSD1306 drivers

 Pick one up today in the adafruit shop!
 ------> http://www.adafruit.com/category/63_98

 This example is for a 128x32 pixel display using I2C to communicate
 3 pins are required to interface (two I2C and one reset).

 Adafruit invests time and resources providing this open
 source code, please support Adafruit and open-source
 hardware by purchasing products from Adafruit!

 Written by Limor Fried/Ladyada for Adafruit Industries,
 with contributions from the open source community.
 BSD license, check license.txt for more information
 All text above, and the splash screen below must be
 included in any redistribution.
 **************************************************************************/

#include <SPI.h>
#include <Wire.h>
#include <Adafruit_GFX.h>
#include <Adafruit_SSD1306.h>

#define SCREEN_WIDTH 128 // OLED display width, in pixels
#define SCREEN_HEIGHT 32 // OLED display height, in pixels

// GPIO 6 pour allumer ecra


// Declaration for an SSD1306 display connected to I2C (SDA, SCL pins)
#define OLED_RESET     -1 // Reset pin # (or -1 if sharing Arduino reset pin)
Adafruit_SSD1306 display(SCREEN_WIDTH, SCREEN_HEIGHT, &Wire, OLED_RESET);

#define NUMFLAKES     10 // Number of snowflakes in the animation example

#define LOGO_HEIGHT   16
#define LOGO_WIDTH    16
static const unsigned char PROGMEM logo_bmp[] =
{ B00000000, B11000000,
  B00000001, B11000000,
  B00000001, B11000000,
  B00000011, B11100000,
  B11110011, B11100000,
  B11111110, B11111000,
  B01111110, B11111111,
  B00110011, B10011111,
  B00011111, B11111100,
  B00001101, B01110000,
  B00011011, B10100000,
  B00111111, B11100000,
  B00111111, B11110000,
  B01111100, B11110000,
  B01110000, B01110000,
  B00000000, B00110000 };

void setup() {

  // power the display on
  pinMode(6, OUTPUT);
  digitalWrite(6, HIGH);   // turn the LED on (HIGH is the voltage level)
  delay(100);
    
  Serial.begin(115200);

  // SSD1306_SWITCHCAPVCC = generate display voltage from 3.3V internally
  if(!display.begin(SSD1306_SWITCHCAPVCC, 0x3C)) { // Address 0x3C for 128x32
    Serial.println(F("SSD1306 allocation failed"));
    for(;;); // Don't proceed, loop forever
  }

  // Show initial display buffer contents on the screen --
  // the library initializes this with an Adafruit splash screen.
  display.display();
  delay(2000); // Pause for 2 seconds

  // Clear the buffer
  display.clearDisplay();

  // Draw a single pixel in white
  display.drawPixel(10, 10, SSD1306_WHITE);

  // Show the display buffer on the screen. You MUST call display() after
  // drawing commands to make them visible on screen!
  display.display();
  delay(2000);
  // display.display() is NOT necessary after every single drawing command,
  // unless that's what you want...rather, you can batch up a bunch of
  // drawing operations and then update the screen all at once by calling
  // display.display(). These examples demonstrate both approaches...

  testdrawline();      // Draw many lines

  testdrawrect();      // Draw rectangles (outlines)

  testfillrect();      // Draw rectangles (filled)

  testdrawcircle();    // Draw circles (outlines)

  testfillcircle();    // Draw circles (filled)

  testdrawroundrect(); // Draw rounded rectangles (outlines)

  testfillroundrect(); // Draw rounded rectangles (filled)

  testdrawtriangle();  // Draw triangles (outlines)

  testfilltriangle();  // Draw triangles (filled)

  testdrawchar();      // Draw characters of the default font

  testdrawstyles();    // Draw 'stylized' characters

  testscrolltext();    // Draw scrolling text

  testdrawbitmap();    // Draw a small bitmap image

  // Invert and restore display, pausing in-between
  display.invertDisplay(true);
  delay(1000);
  display.invertDisplay(false);
  delay(1000);

  testanimate(logo_bmp, LOGO_WIDTH, LOGO_HEIGHT); // Animate bitmaps
}

void loop() {
}

void testdrawline() {
  int16_t i;

  display.clearDisplay(); // Clear display buffer

  for(i=0; i<display.width(); i+=4) {
    display.drawLine(0, 0, i, display.height()-1, SSD1306_WHITE);
    display.display(); // Update screen with each newly-drawn line
    delay(1);
  }
  for(i=0; i<display.height(); i+=4) {
    display.drawLine(0, 0, display.width()-1, i, SSD1306_WHITE);
    display.display();
    delay(1);
  }
  delay(250);

  display.clearDisplay();

  for(i=0; i<display.width(); i+=4) {
    display.drawLine(0, display.height()-1, i, 0, SSD1306_WHITE);
    display.display();
    delay(1);
  }
  for(i=display.height()-1; i>=0; i-=4) {
    display.drawLine(0, display.height()-1, display.width()-1, i, SSD1306_WHITE);
    display.display();
    delay(1);
  }
  delay(250);

  display.clearDisplay();

  for(i=display.width()-1; i>=0; i-=4) {
    display.drawLine(display.width()-1, display.height()-1, i, 0, SSD1306_WHITE);
    display.display();
    delay(1);
  }
  for(i=display.height()-1; i>=0; i-=4) {
    display.drawLine(display.width()-1, display.height()-1, 0, i, SSD1306_WHITE);
    display.display();
    delay(1);
  }
  delay(250);

  display.clearDisplay();

  for(i=0; i<display.height(); i+=4) {
    display.drawLine(display.width()-1, 0, 0, i, SSD1306_WHITE);
    display.display();
    delay(1);
  }
  for(i=0; i<display.width(); i+=4) {
    display.drawLine(display.width()-1, 0, i, display.height()-1, SSD1306_WHITE);
    display.display();
    delay(1);
  }

  delay(2000); // Pause for 2 seconds
}

void testdrawrect(void) {
  display.clearDisplay();

  for(int16_t i=0; i<display.height()/2; i+=2) {
    display.drawRect(i, i, display.width()-2*i, display.height()-2*i, SSD1306_WHITE);
    display.display(); // Update screen with each newly-drawn rectangle
    delay(1);
  }

  delay(2000);
}

void testfillrect(void) {
  display.clearDisplay();

  for(int16_t i=0; i<display.height()/2; i+=3) {
    // The INVERSE color is used so rectangles alternate white/black
    display.fillRect(i, i, display.width()-i*2, display.height()-i*2, SSD1306_INVERSE);
    display.display(); // Update screen with each newly-drawn rectangle
    delay(1);
  }

  delay(2000);
}

void testdrawcircle(void) {
  display.clearDisplay();

  for(int16_t i=0; i<max(display.width(),display.height())/2; i+=2) {
    display.drawCircle(display.width()/2, display.height()/2, i, SSD1306_WHITE);
    display.display();
    delay(1);
  }

  delay(2000);
}

void testfillcircle(void) {
  display.clearDisplay();

  for(int16_t i=max(display.width(),display.height())/2; i>0; i-=3) {
    // The INVERSE color is used so circles alternate white/black
    display.fillCircle(display.width() / 2, display.height() / 2, i, SSD1306_INVERSE);
    display.display(); // Update screen with each newly-drawn circle
    delay(1);
  }

  delay(2000);
}

void testdrawroundrect(void) {
  display.clearDisplay();

  for(int16_t i=0; i<display.height()/2-2; i+=2) {
    display.drawRoundRect(i, i, display.width()-2*i, display.height()-2*i,
      display.height()/4, SSD1306_WHITE);
    display.display();
    delay(1);
  }

  delay(2000);
}

void testfillroundrect(void) {
  display.clearDisplay();

  for(int16_t i=0; i<display.height()/2-2; i+=2) {
    // The INVERSE color is used so round-rects alternate white/black
    display.fillRoundRect(i, i, display.width()-2*i, display.height()-2*i,
      display.height()/4, SSD1306_INVERSE);
    display.display();
    delay(1);
  }

  delay(2000);
}

void testdrawtriangle(void) {
  display.clearDisplay();

  for(int16_t i=0; i<max(display.width(),display.height())/2; i+=5) {
    display.drawTriangle(
      display.width()/2  , display.height()/2-i,
      display.width()/2-i, display.height()/2+i,
      display.width()/2+i, display.height()/2+i, SSD1306_WHITE);
    display.display();
    delay(1);
  }

  delay(2000);
}

void testfilltriangle(void) {
  display.clearDisplay();

  for(int16_t i=max(display.width(),display.height())/2; i>0; i-=5) {
    // The INVERSE color is used so triangles alternate white/black
    display.fillTriangle(
      display.width()/2  , display.height()/2-i,
      display.width()/2-i, display.height()/2+i,
      display.width()/2+i, display.height()/2+i, SSD1306_INVERSE);
    display.display();
    delay(1);
  }

  delay(2000);
}

void testdrawchar(void) {
  display.clearDisplay();

  display.setTextSize(1);      // Normal 1:1 pixel scale
  display.setTextColor(SSD1306_WHITE); // Draw white text
  display.setCursor(0, 0);     // Start at top-left corner
  display.cp437(true);         // Use full 256 char 'Code Page 437' font

  // Not all the characters will fit on the display. This is normal.
  // Library will draw what it can and the rest will be clipped.
  for(int16_t i=0; i<256; i++) {
    if(i == '\n') display.write(' ');
    else          display.write(i);
  }

  display.display();
  delay(2000);
}

void testdrawstyles(void) {
  display.clearDisplay();

  display.setTextSize(1);             // Normal 1:1 pixel scale
  display.setTextColor(SSD1306_WHITE);        // Draw white text
  display.setCursor(0,0);             // Start at top-left corner
  display.println(F("Hello, world!"));

  display.setTextColor(SSD1306_BLACK, SSD1306_WHITE); // Draw 'inverse' text
  display.println(3.141592);

  display.setTextSize(2);             // Draw 2X-scale text
  display.setTextColor(SSD1306_WHITE);
  display.print(F("0x")); display.println(0xDEADBEEF, HEX);

  display.display();
  delay(2000);
}

void testscrolltext(void) {
  display.clearDisplay();

  display.setTextSize(2); // Draw 2X-scale text
  display.setTextColor(SSD1306_WHITE);
  display.setCursor(10, 0);
  display.println(F("scroll"));
  display.display();      // Show initial text
  delay(100);

  // Scroll in various directions, pausing in-between:
  display.startscrollright(0x00, 0x0F);
  delay(2000);
  display.stopscroll();
  delay(1000);
  display.startscrollleft(0x00, 0x0F);
  delay(2000);
  display.stopscroll();
  delay(1000);
  display.startscrolldiagright(0x00, 0x07);
  delay(2000);
  display.startscrolldiagleft(0x00, 0x07);
  delay(2000);
  display.stopscroll();
  delay(1000);
}

void testdrawbitmap(void) {
  display.clearDisplay();

  display.drawBitmap(
    (display.width()  - LOGO_WIDTH ) / 2,
    (display.height() - LOGO_HEIGHT) / 2,
    logo_bmp, LOGO_WIDTH, LOGO_HEIGHT, 1);
  display.display();
  delay(1000);
}

#define XPOS   0 // Indexes into the 'icons' array in function below
#define YPOS   1
#define DELTAY 2

void testanimate(const uint8_t *bitmap, uint8_t w, uint8_t h) {
  int8_t f, icons[NUMFLAKES][3];

  // Initialize 'snowflake' positions
  for(f=0; f< NUMFLAKES; f++) {
    icons[f][XPOS]   = random(1 - LOGO_WIDTH, display.width());
    icons[f][YPOS]   = -LOGO_HEIGHT;
    icons[f][DELTAY] = random(1, 6);
    Serial.print(F("x: "));
    Serial.print(icons[f][XPOS], DEC);
    Serial.print(F(" y: "));
    Serial.print(icons[f][YPOS], DEC);
    Serial.print(F(" dy: "));
    Serial.println(icons[f][DELTAY], DEC);
  }

  for(;;) { // Loop forever...
    display.clearDisplay(); // Clear the display buffer

    // Draw each snowflake:
    for(f=0; f< NUMFLAKES; f++) {
      display.drawBitmap(icons[f][XPOS], icons[f][YPOS], bitmap, w, h, SSD1306_WHITE);
    }

    display.display(); // Show the display buffer on the screen
    delay(200);        // Pause for 1/10 second

    // Then update coordinates of each flake...
    for(f=0; f< NUMFLAKES; f++) {
      icons[f][YPOS] += icons[f][DELTAY];
      // If snowflake is off the bottom of the screen...
      if (icons[f][YPOS] >= display.height()) {
        // Reinitialize to a random position, just off the top
        icons[f][XPOS]   = random(1 - LOGO_WIDTH, display.width());
        icons[f][YPOS]   = -LOGO_HEIGHT;
        icons[f][DELTAY] = random(1, 6);
      }
    }
  }
}

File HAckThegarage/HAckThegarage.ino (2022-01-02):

// the setup function runs once when you press reset or power the board
void setup() {
  // initialize digital pin LED_BUILTIN as an output.
  pinMode(14, OUTPUT);
  pinMode(21, OUTPUT);
  
  
}

// the loop function runs over and over again forever
void loop() {
  digitalWrite(14, HIGH);   // turn the LED on (HIGH is the voltage level)
  digitalWrite(21, LOW);   // turn the LED on (HIGH is the voltage level)

  delay(1000);                       // wait for a second
  digitalWrite(14, LOW);    // turn the LED off by making the voltage LOW
  digitalWrite(21, HIGH);   // turn the LED on (HIGH is the voltage level)

  delay(1000);                       // wait for a second
}
